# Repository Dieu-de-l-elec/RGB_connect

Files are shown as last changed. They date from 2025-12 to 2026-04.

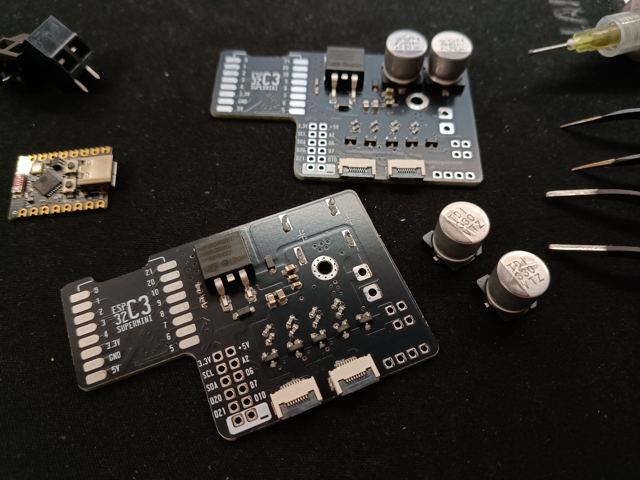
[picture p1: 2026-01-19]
BUILD/build06.jpg

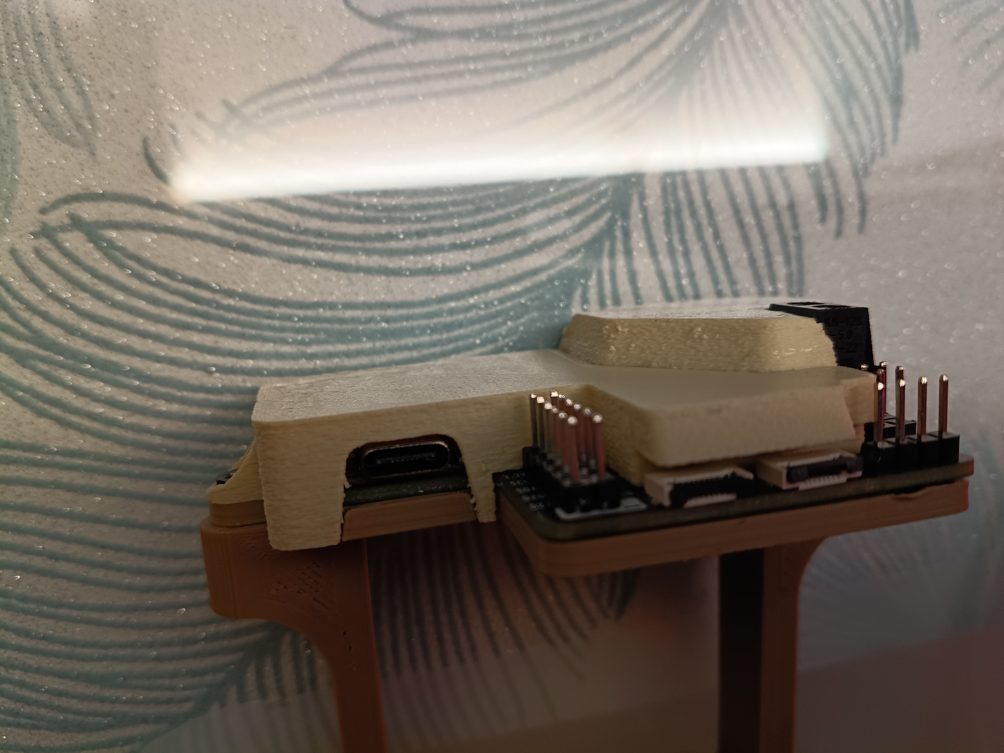
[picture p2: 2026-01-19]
BUILD/build02.jpg

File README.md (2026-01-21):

# RGB_connect: An ESP32 powered RGB LED driver with 5 channels:

This RGB LED driver built around an ESP32 comes with 5 P channel Mosfets and a 3.3V LDO voltage regulator.
Controlling the ESP32 is possible thanks to a Blynk Dashboard accessible from a phone or a laptop. With it's 5 Mosfets, this module can control everything that needs switching 5 high sink loads (up to 5 Amps), but this board has been specifically design for the 3 R, G and B channels, with the 2 other channels remaining for white LED strips.

PCB RENDER 01 RGB CONNECT FINAL RENDERS 01

# Key features
- **ESP32 C3** supermini devboard based
- Input voltage from **6 to 24V** (recommended)
- screw terminal for Input voltage
- L7805AB **5.0V LDO voltage regulator**
- **x5 P-channel MOSFETs** (AO3400)
- **x2 8P FPCs** and **2.54mm Header** for accessing IOs including I²C lines.
- **Blynk integration** for easy control

# PCB Design
2 Layer PCB designed in EASYEDA (Pro edition)

# Schematic

SCHEMATIC

# PCB Layout

PCB LAYOUT 1
PCB LAYOUT 2
PCB Part3 3d model top
PCB Part4 3d model bottom

# CAD (case for the PCB)

RGB CONNECT FINAL RENDERS 01
Designed in Fusion 360

# Renders

PCB RENDER 01
PCB RENDER 02
PCB RENDER 03
PCB RENDER 04

RGB CONNECT FINAL RENDERS 02
RGB CONNECT FINAL RENDERS 04

RGB CONNECT FINAL RENDERS 07
RGB CONNECT FINAL RENDERS 03

RGB CONNECT FINAL RENDERS 08

RGB CONNECT FINAL RENDERS 08

RGB CONNECT FINAL RENDERS 05

# Important notice:

When carefully looking at the PCBs, I noticed that the silkscreen on the screw terminal (+ and -) where flipped! 
Be careful when connecting the 12V power supply!

# Once built:

The case is printed with a duo beige-brown, and it looks pretty good with the black soldermask and FR4. 
I've also designed and 3d printed a brown bracket.





build01
build04

# demo with the blynk app:

working

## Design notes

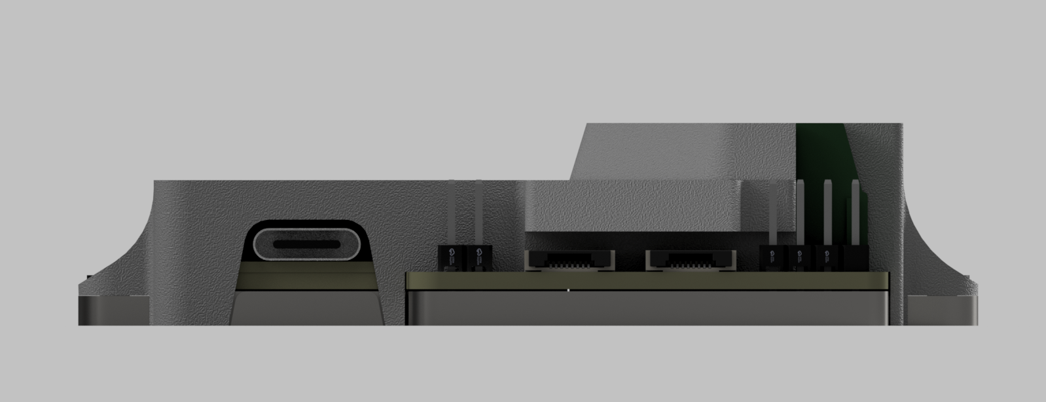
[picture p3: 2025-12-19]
RENDERS/RGB CONNECT FINAL RENDERS 07.png

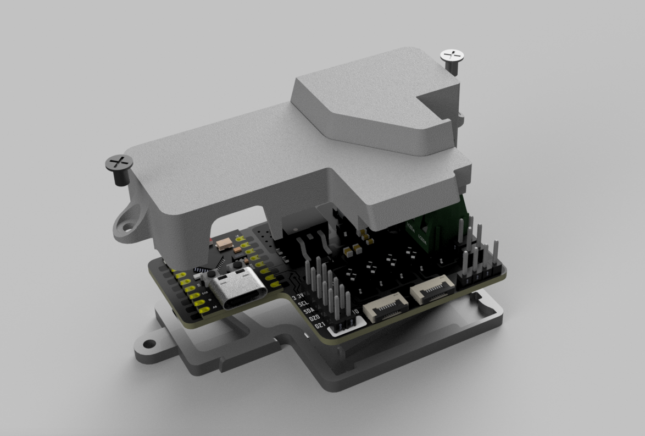
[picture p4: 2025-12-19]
RENDERS/RGB CONNECT FINAL RENDERS 05.png

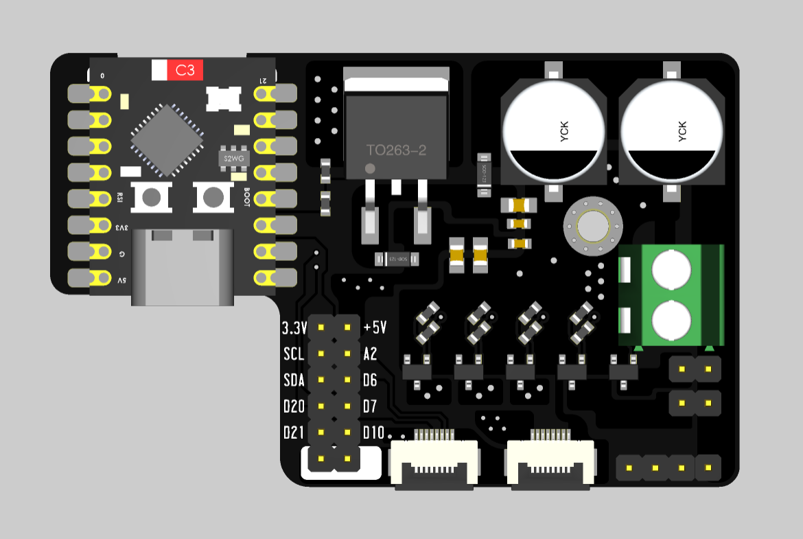
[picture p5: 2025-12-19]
RENDERS/PCB 3d Model EASYEDA Viewer Top.png

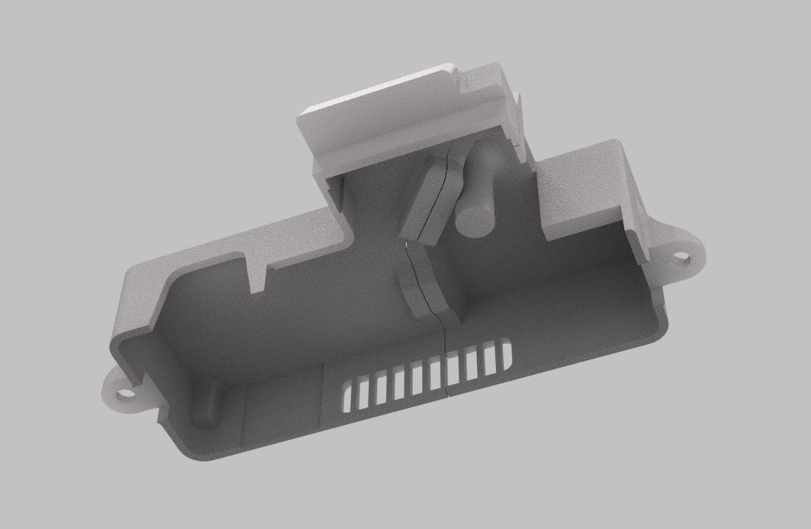
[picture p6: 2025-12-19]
RENDERS/RGB CONNECT FINAL RENDERS 08.png

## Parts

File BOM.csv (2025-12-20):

Qty | Component | Attribute | Value
1 | ESP32 C3 supermini board
2 | 2.54mm Male Header |  | 2P
1 | 2.54mm Male Header |  | 4P
2 | 2.54mm Male Header |  | 6P
2 | Capacitor | CAP-SMD_BD10.0-L10.3-W10.3-LS11.0-FD 330uF 35TZV330M10X10.5 Rubycon | 330µF
2 | Capacitor | 0805 | 10µF
2 | Capacitor | 0603 | 100nF
1 | Capacitor | 0805 | 22µF
2 | Diode | SOD-123 | 1N5819HW-7-F
2 | FPC connector | FPC-05F-8PH20 | 8P
1 | Screw Terminal | WJ128V-5.0-2P | 2P
5 | AO3400 | SOT-23-3
5 | Resistor | 0603 | 1.2K
5 | Resistor | 0603 | 20K
1 | LDO Voltage regulator | L7805ABD2T-TR | 5.0V
 | 3d Printed Case

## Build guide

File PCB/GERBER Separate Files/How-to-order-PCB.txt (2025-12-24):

How to Order PCB

Please refer to:
https://prodocs.easyeda.com/en/pcb/order-order-pcb/index.html

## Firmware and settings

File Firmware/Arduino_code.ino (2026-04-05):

#define BLYNK_TEMPLATE_ID "......................."
#define BLYNK_TEMPLATE_NAME "RGB Connect" 
#define BLYNK_AUTH_TOKEN "........................"


#include "WiFi.h"
#include <WiFiClient.h>
#include <BlynkSimpleEsp32.h>

// Your WiFi credentials.
// Set password to "" for open networks.
char ssid[] = ".....................";
char pass[] = ".....................";


int redValue = 0;
int greenValue = 0;
int blueValue = 0;
int CWValue = 0;
int WWValue = 0;


#define RED_PIN  3
#define GREEN_PIN 4
#define BLUE_PIN  5

#define CW  0
#define WW  1

BLYNK_WRITE(V0) {  // Red
  redValue = param.asInt();
  analogWrite(RED_PIN, redValue);
  Serial.println(redValue);
}

BLYNK_WRITE(V1) {  // Green
  greenValue = param.asInt();
  analogWrite(GREEN_PIN, greenValue);
  Serial.println(greenValue);
}

BLYNK_WRITE(V2) {  // Blue
  blueValue = param.asInt();
  analogWrite(BLUE_PIN, blueValue);
  Serial.println(blueValue);
}

BLYNK_WRITE(V4) {  // Cold White
  CWValue = param.asInt();
  analogWrite(CW, CWValue);
  Serial.println(CWValue);
}

BLYNK_WRITE(V3) {  // Warm White
  WWValue = param.asInt();
  analogWrite(WW, WWValue);
  Serial.println(WWValue);
}

void setup()
{
  Blynk.begin(BLYNK_AUTH_TOKEN, ssid, pass);
}

void loop()
{
  Blynk.run();
}
